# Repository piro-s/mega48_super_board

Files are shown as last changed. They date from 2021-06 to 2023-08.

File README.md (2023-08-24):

## mega48_super_board  
Development board for Atmega48 developed by me and [mostovsky](https://github.com/mostovsky).  
Description for version v0.1 go to [this](docs/mega48_super_board_v0.1.md).  
Description for version v0.2 (some errors) go to [this](docs/mega48_super_board_v0.2.md).  

---
Version 0.3:  
1. Power supply from 7V to 15V or just 5V.  
2. Reverse polarity protection.  
3. There are separate connectors for external power, 5V, 3.3V and ground.  
4. Separate connectors for each pin of the MCU (except reset, xtal and power), compatible with prototyping board.  
5. External quartz at 8 MHz.  
6. Programming via USBasp.  
7. LED to indicate power and reset.  

Board size: 23x71 mm.  
Version 0.3 is the corrected version 0.2.  

---
#### scheme:  
scheme_v0.1:  
[pdf](docs/scheme_v0.1.pdf)  
scheme_v0.3:  
[pdf](docs/scheme_v0.3.pdf)  

---
#### helper:  
helper_v0.1:  
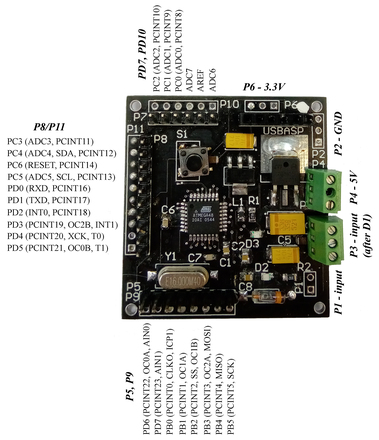
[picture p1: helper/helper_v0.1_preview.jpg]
helper_v0.1
  
helper_v0.3 (also v0.2):  
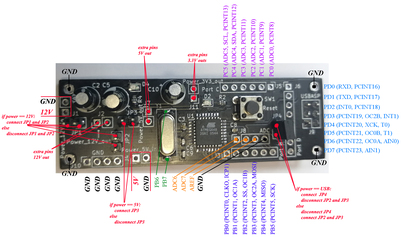
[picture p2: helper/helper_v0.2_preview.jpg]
helper_v0.3
  

---
#### pcb:  
##### pcb_v0.1:  
top screen:  
top_screen  
bottom_screen:  
bottom_screen  
##### pcb_v0.3:  
top screen:  
top_screen  
bottom_screen:  
bottom_screen  

---
#### work:  
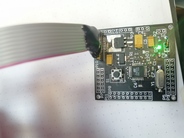
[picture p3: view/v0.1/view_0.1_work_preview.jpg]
work
  
AVRdude:  
AVRdude  

---
#### gerber:  
Archive for production:  
[gerber_v0.1](https://github.com/piro-s/mega48_super_board/raw/main/gerber/mega48_super_board_v0.1.zip)  
[gerber_v0.3](https://github.com/piro-s/mega48_super_board/raw/main/gerber/mega48_super_board_v0.3.zip)

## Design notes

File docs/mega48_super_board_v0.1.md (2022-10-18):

# mega48_super_board  
Development board for Atmega48 developed by me and [mostovsky](https://github.com/mostovsky).  

Version 0.1: 
1. Power supply from 7V to 15V.  
2. There are separate connectors for external power, 5V, 3.3V and ground.  
3. Separate paired connectors for each pin of the MCU (except reset, xtal and power).  
4. Series protection resistors to each output pin.  
5. External quartz at 8 MHz.  
6. Programming via USBasp.  
7. LED to indicate power and reset.  

Version v0.1 fully functional. Board size: 48x45 mm.  

***
## scheme:  
### scheme_v0.1:  
[pdf](scheme_v0.1.pdf)  

***
## helper:  
### helper_v0.1:  
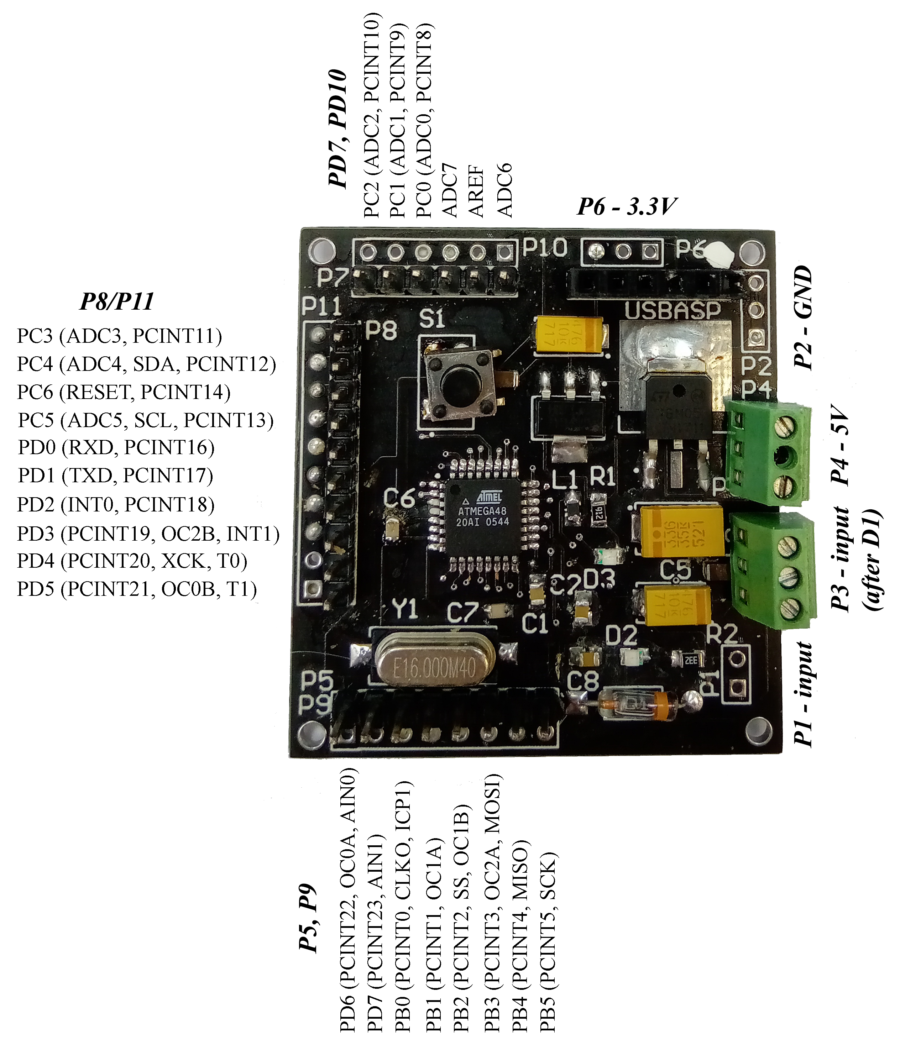
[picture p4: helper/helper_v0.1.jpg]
helper_v0.1
  

***
## pcb:  
### pcb_v0.1:  
#### top screen:  
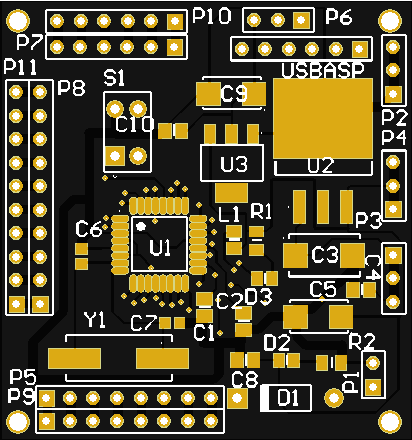
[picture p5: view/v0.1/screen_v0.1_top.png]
top_screen
  
#### top assambled:  
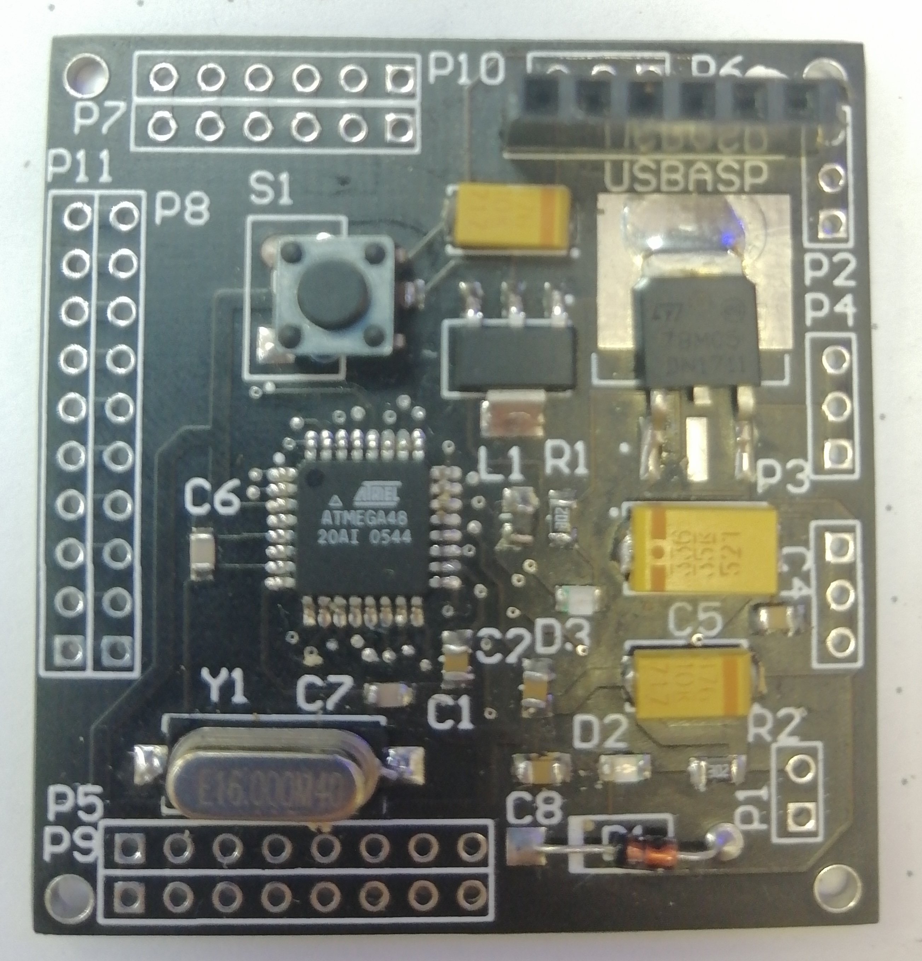
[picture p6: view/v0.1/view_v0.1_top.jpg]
top_assambled
  
#### bottom screen:  
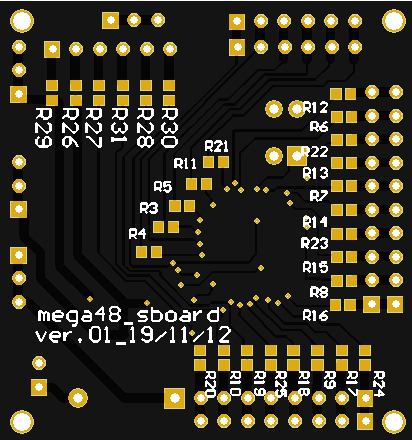
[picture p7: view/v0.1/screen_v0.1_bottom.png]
bottom_screen
  
#### bottom assambled:  
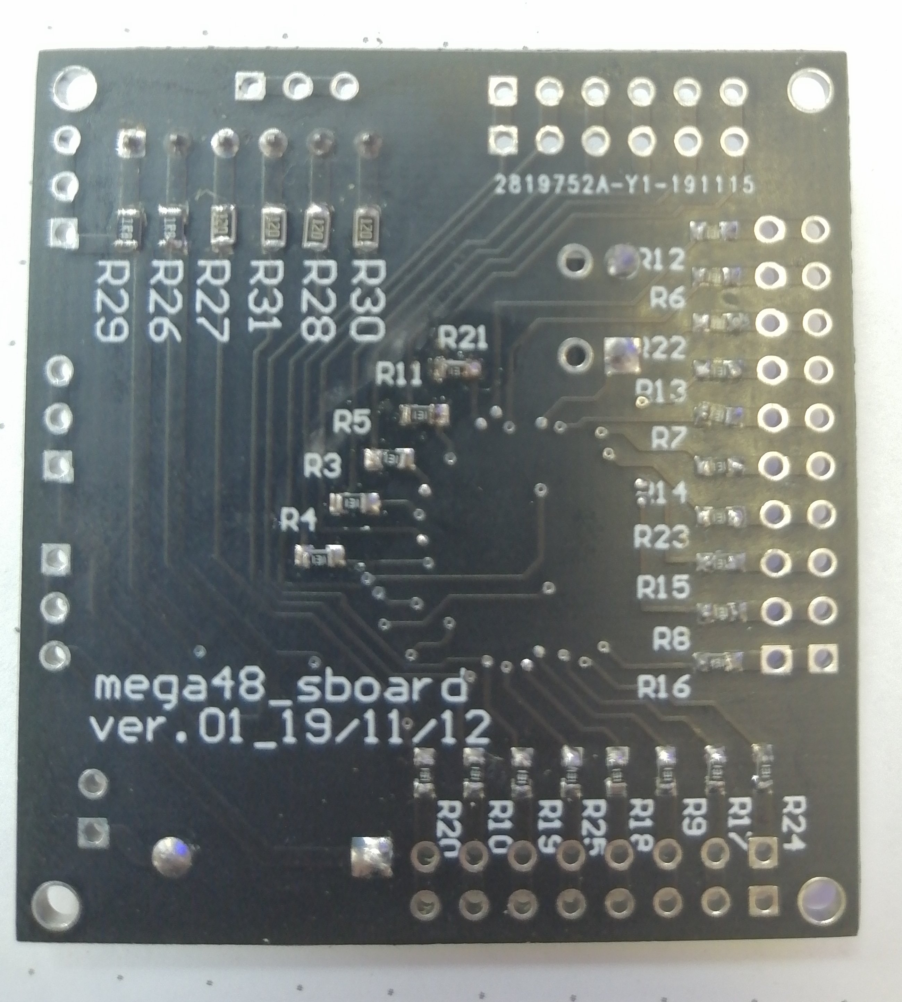
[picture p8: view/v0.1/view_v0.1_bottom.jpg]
bottom_assambled
  

***
## work:  
### work:  
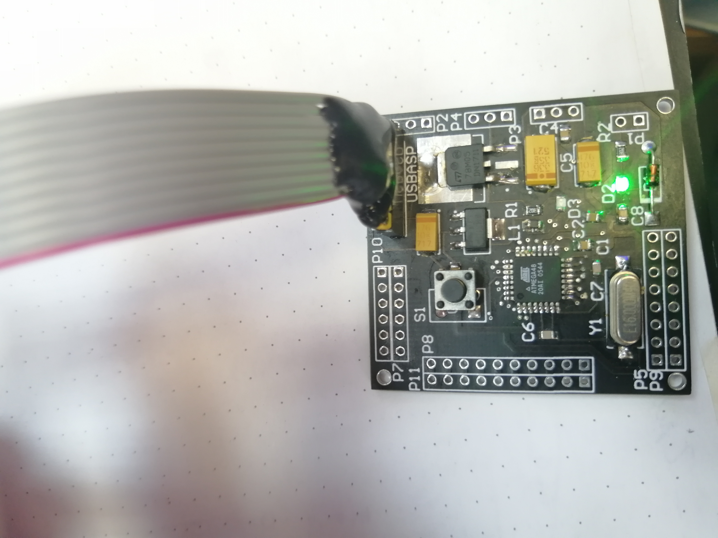
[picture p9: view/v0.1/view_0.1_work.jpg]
work
  
### AVRdude:  
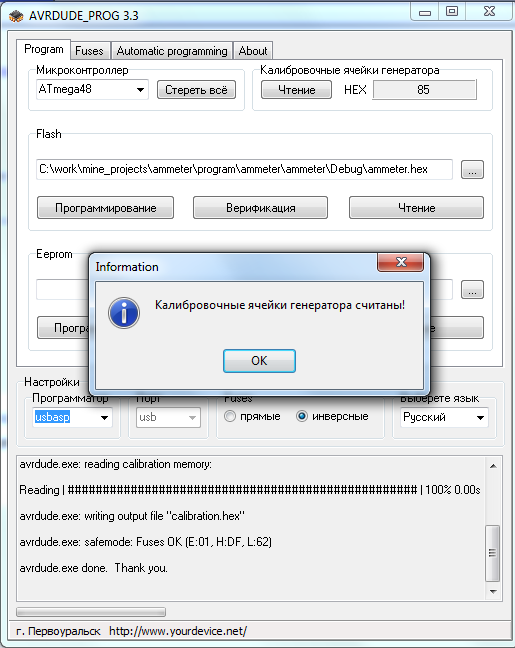
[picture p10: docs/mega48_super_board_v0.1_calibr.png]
AVRdude
  

***
## gerber:  
Archive for production:  
[gerber_v0.1](https://github.com/piro-s/mega48_super_board/raw/main/gerber/mega48_super_board_v0.1.zip)

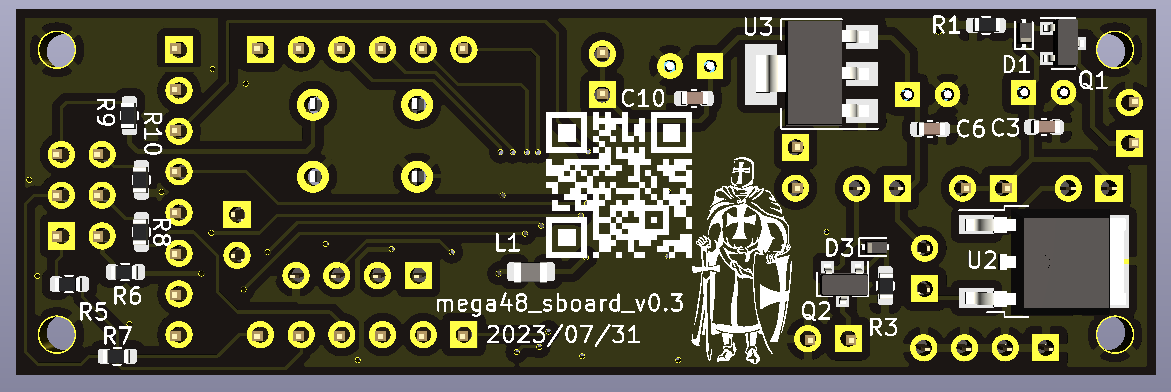
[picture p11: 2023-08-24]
view/v0.3/screen_v0.3_bottom.png

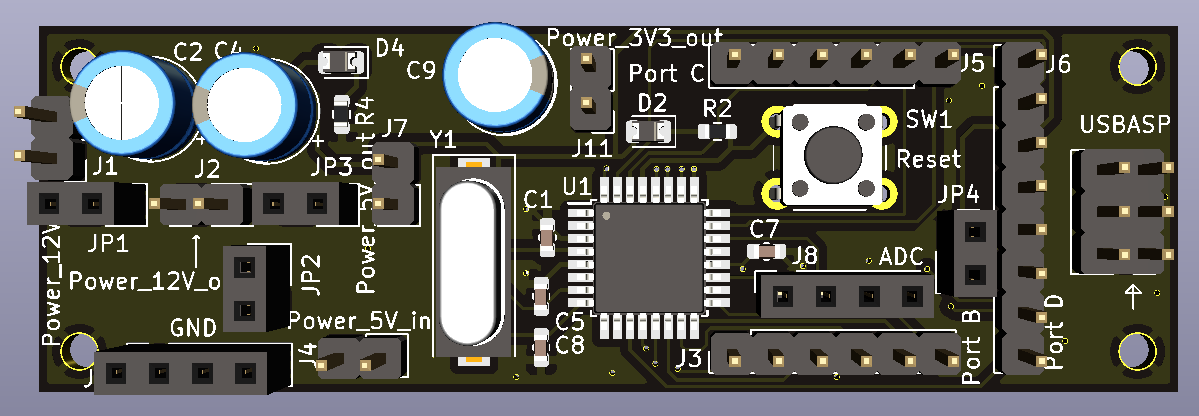
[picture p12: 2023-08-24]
view/v0.3/screen_v0.3_top.png

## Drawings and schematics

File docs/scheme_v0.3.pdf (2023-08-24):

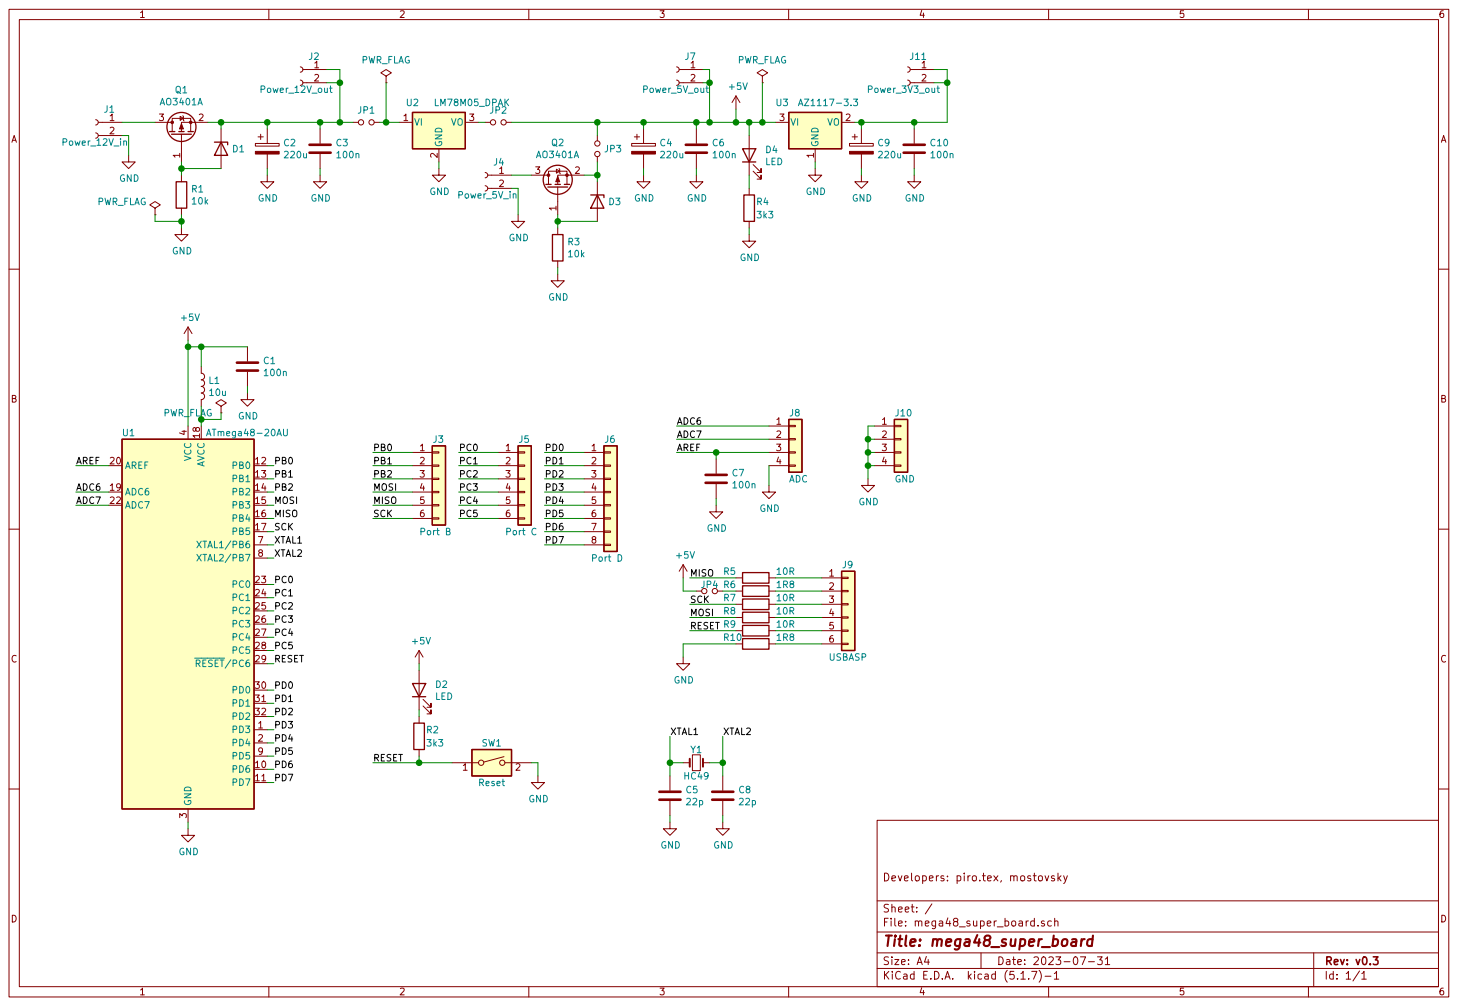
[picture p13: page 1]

File: mega48_super_board.sch Sheet: / Developers: piro.tex, mostovsky

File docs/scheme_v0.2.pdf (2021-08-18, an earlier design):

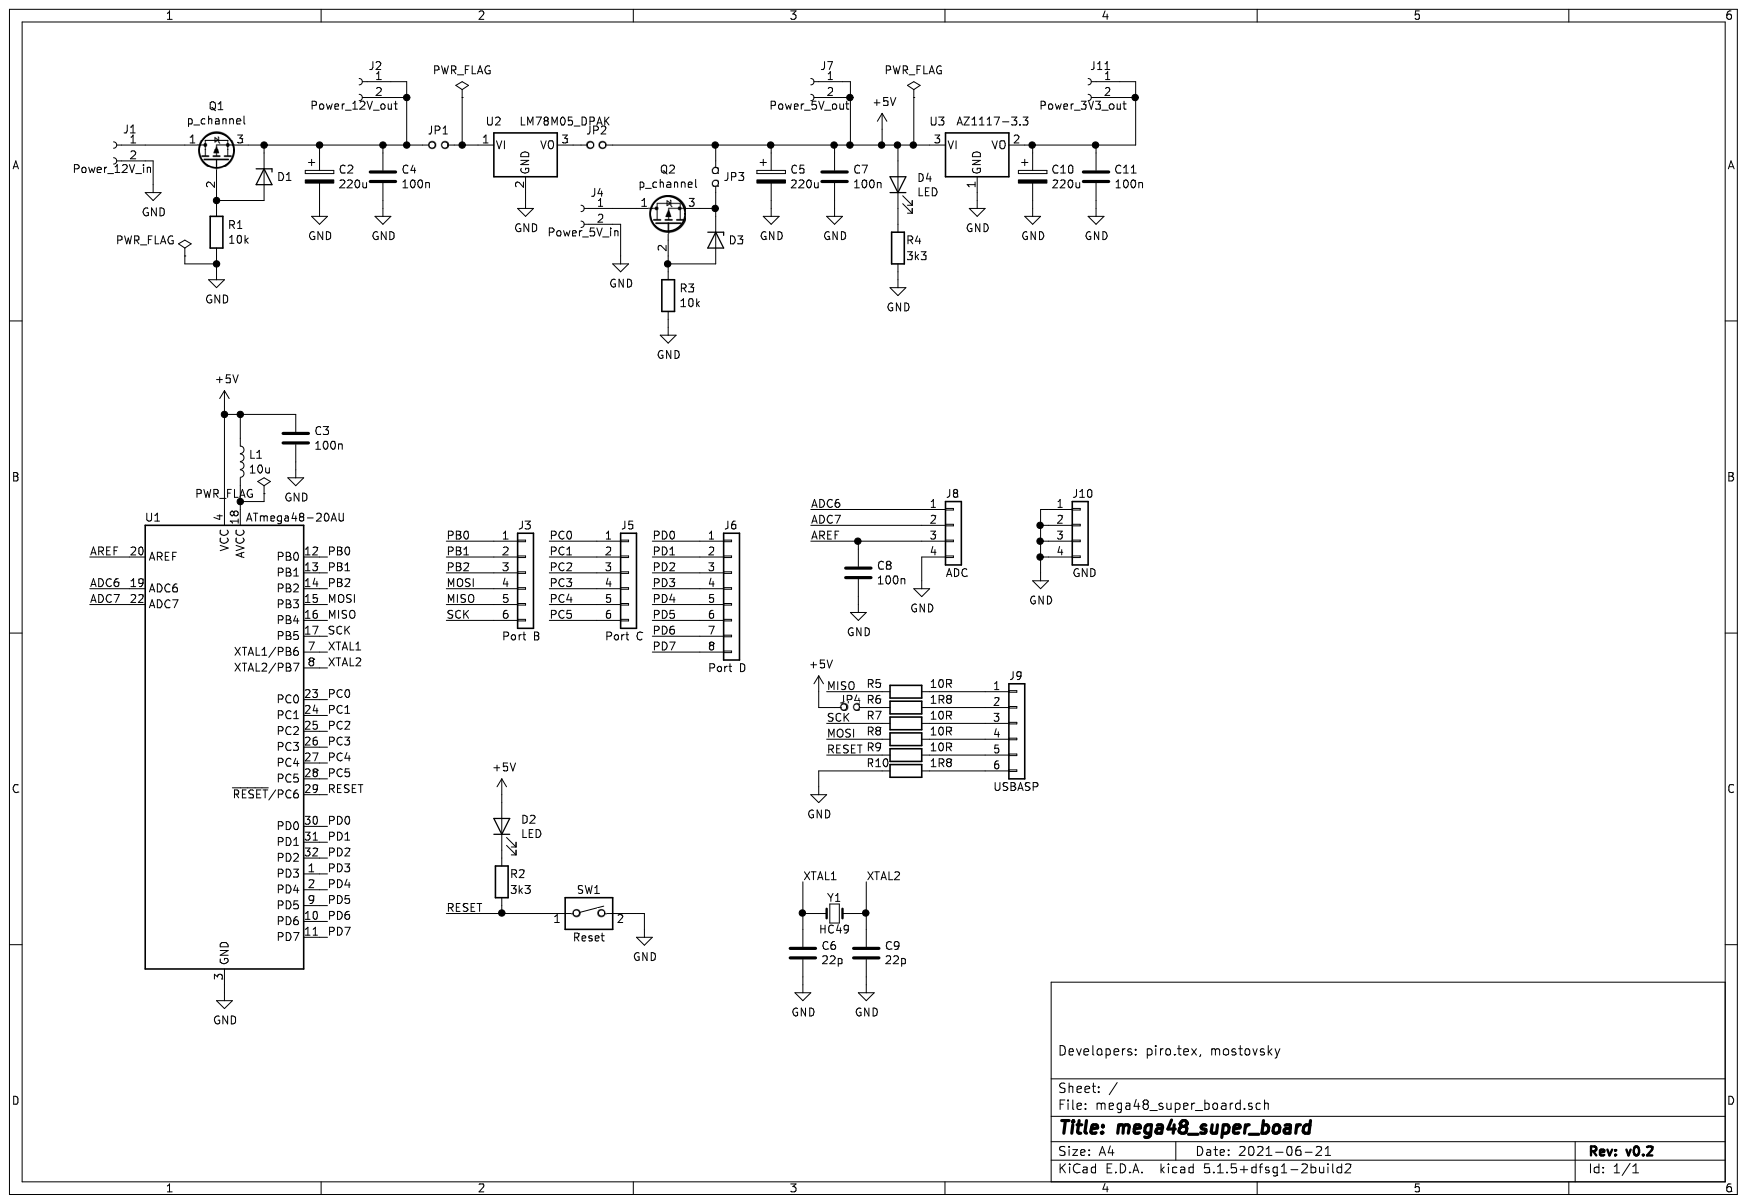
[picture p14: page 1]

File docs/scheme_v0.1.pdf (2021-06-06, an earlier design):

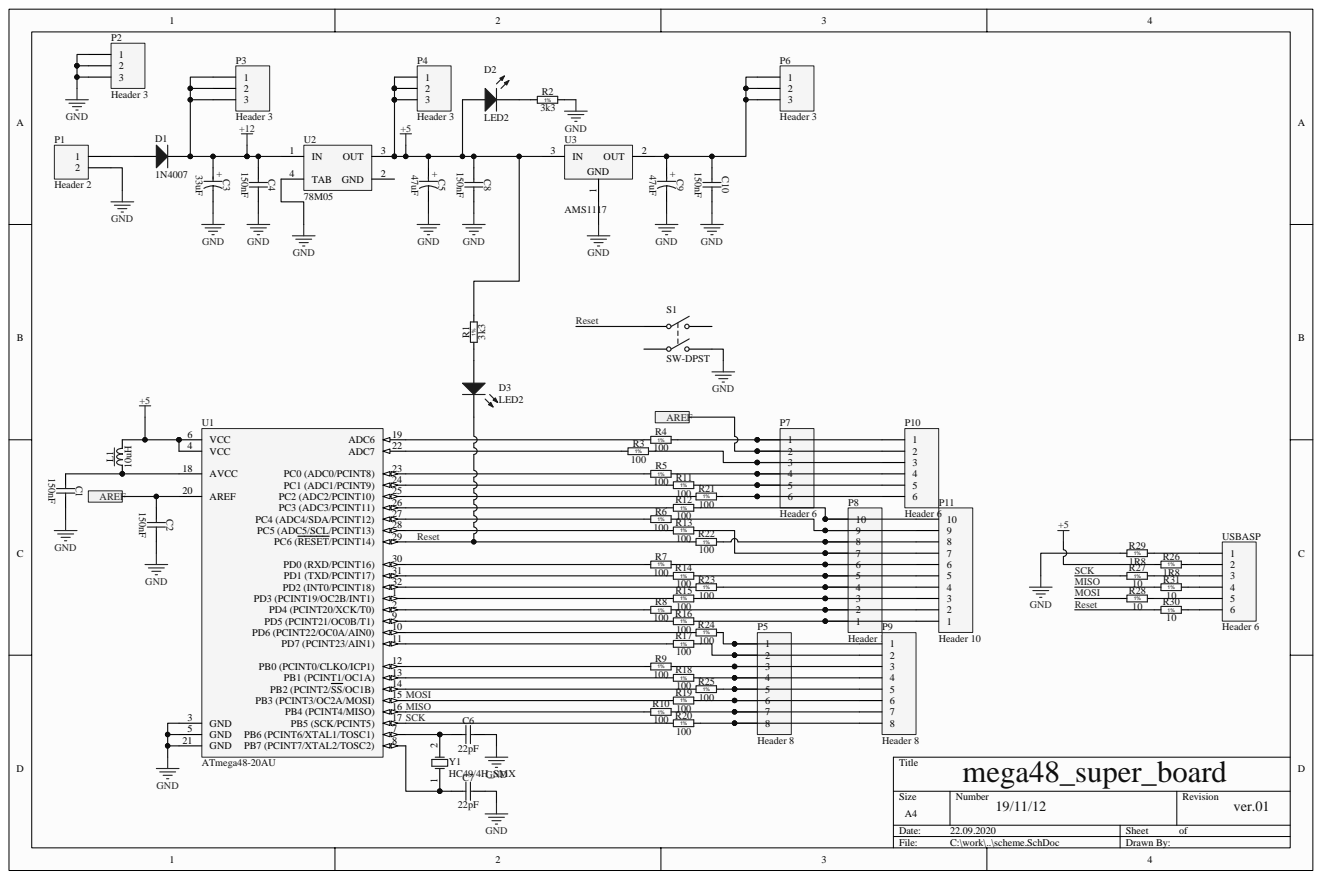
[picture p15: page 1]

1% 100 R6 Header 6 100 1% R13 | 10 9 8 7 6 | Header 6 | 10 9 8 7 6 5 4 3 2 1

1% 100 R15 | 3
1% 100 R8 | 2

MOSI 1% 100 R19 | 6
MISO 1% 100 R10 | 7
100 1% R20 SCK | 8

Size A4 | Number 19/11/12 | Revision ver.01

Date: 22.09.2020 | Sheet of
File: C:\work\..\scheme.SchDoc | Drawn By:

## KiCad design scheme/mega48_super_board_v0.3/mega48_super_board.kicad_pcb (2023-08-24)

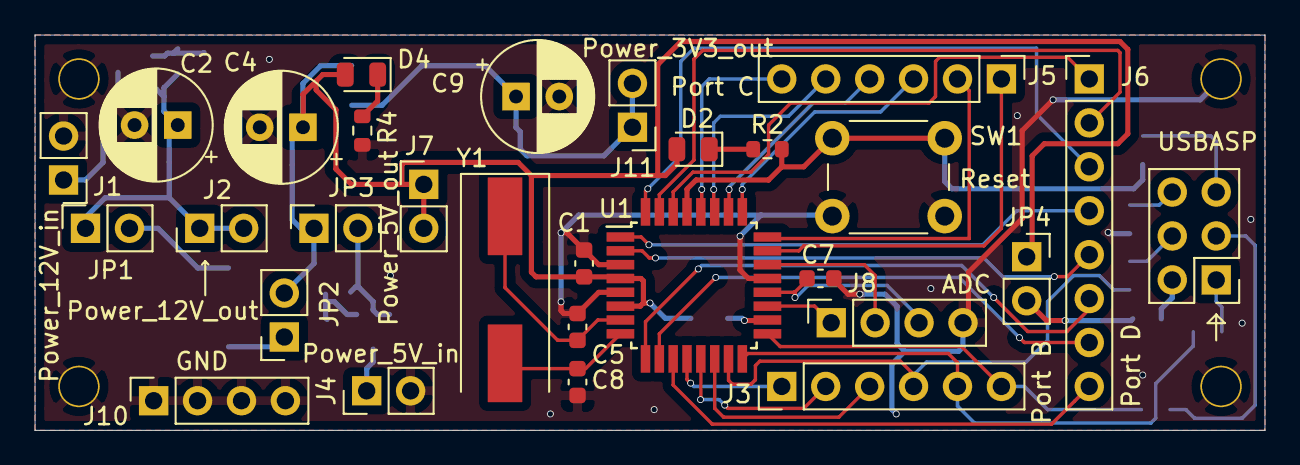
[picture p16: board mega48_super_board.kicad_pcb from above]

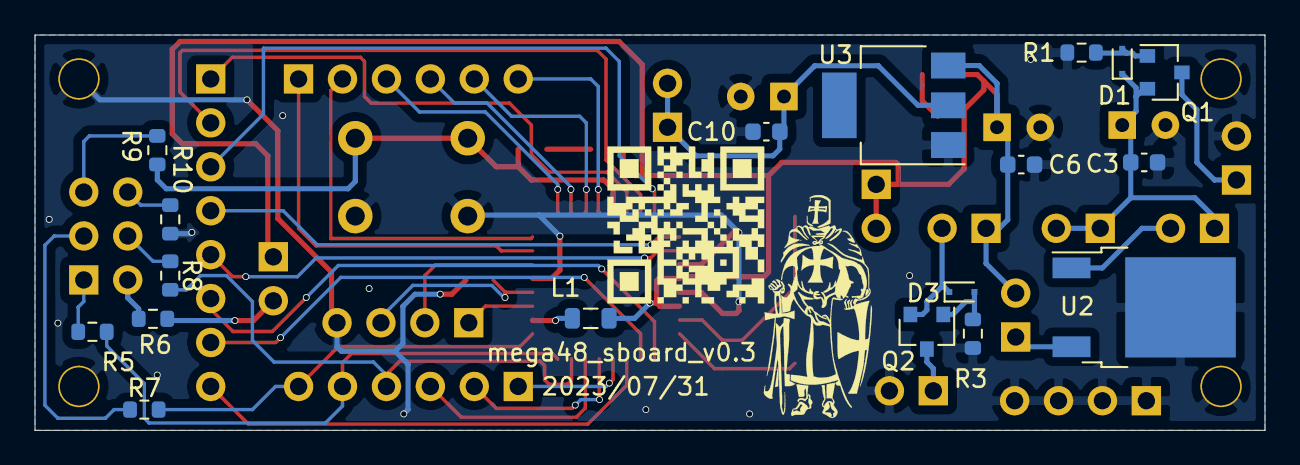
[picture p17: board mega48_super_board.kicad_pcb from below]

Board: 2 copper layers, 71.1 x 22.9 mm, 47 parts (18 on the bottom side), 47 nets.

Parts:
C1, C3, C6, C7, C10: 100n; C_0603_1608Metric
C2, C4, C9: 220u; CP_Radial_D6.3mm_P2.50mm
C5, C8: 22p; C_0603_1608Metric
D1, D3: BZX84Cxx; D_SC-80
D2, D4: LED; D_0805_2012Metric
J1: Power_12V_in; PinHeader_1x02_P2.54mm_Vertical
J2: Power_12V_out; PinHeader_1x02_P2.54mm_Vertical
J3: Port B; PinHeader_1x06_P2.54mm_Vertical
J4: Power_5V_in; PinHeader_1x02_P2.54mm_Vertical
J5: Port C; PinHeader_1x06_P2.54mm_Vertical
J6: Port D; PinHeader_1x08_P2.54mm_Vertical
J7: Power_5V_out; PinHeader_1x02_P2.54mm_Vertical
J8: ADC; PinSocket_1x04_P2.54mm_Vertical
J9: USBASP; PinHeader_2x03_P2.54mm_Vertical
J10: GND; PinSocket_1x04_P2.54mm_Vertical
J11: Power_3V3_out; PinHeader_1x02_P2.54mm_Vertical
JP1, JP2, JP3, JP4: Jumper_NO_Small; PinSocket_1x02_P2.54mm_Vertical
L1: 10u; L_0805_2012Metric
Q1, Q2: AO3401A; SOT-23
R1, R3: 10k; R_0603_1608Metric
R2, R4: 3k3; R_0603_1608Metric
R5, R7, R8, R9: 10R; R_0603_1608Metric
R6, R10: 1R8; R_0603_1608Metric
SW1: Reset; SW_PUSH_6mm
U1: ATmega48-20AU; TQFP-32_7x7mm_P0.8mm
U2: LM78M05_DPAK; TO-252-2
U3: AZ1117-3.3; SOT-223
Y1: HC49; Crystal_SMD_HC49-SD

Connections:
+5V: C1.1, C4.1, C6.1, D2.2, D4.2, J7.1, J7.2, JP2.2, JP3.1, JP4.1, L1.1, U1.4, U1.6, U3.3
/ADC6: J8.1, U1.19
/ADC7: J8.2, U1.22
/AREF: C7.1, J8.3, U1.20
/MISO: J3.5, R5.2, U1.16
/MOSI: J3.4, R8.2, U1.15
/PB0: J3.1, U1.12
/PB1: J3.2, U1.13
/PB2: J3.3, U1.14
/PC0: J5.1, U1.23
/PC1: J5.2, U1.24
/PC2: J5.3, U1.25
/PC3: J5.4, U1.26
/PC4: J5.5, U1.27
/PC5: J5.6, U1.28
/PD0: J6.1, U1.30
/PD1: J6.2, U1.31
/PD2: J6.3, U1.32
/PD3: J6.4, U1.1
/PD4: J6.5, U1.2
/PD5: J6.6, U1.9
/PD6: J6.7, U1.10
/PD7: J6.8, U1.11
/RESET: R2.2, R9.2, SW1.1, U1.29
/SCK: J3.6, R7.2, U1.17
/XTAL1: C5.1, U1.7, Y1.1
/XTAL2: C8.1, U1.8, Y1.2
GND: C1.2, C2.2, C3.2, C4.2, C5.2, C6.2, C7.2, C8.2, C9.2, C10.2, J1.2, J4.2, J8.4, J10.1, J10.2, J10.3, J10.4, R1.2, R3.2, R4.2, R10.2, SW1.2, U1.3, U1.5, U1.21, U2.2, U3.1
unnamed: C2.1, C3.1, D1.1, J2.1, J2.2, JP1.1, Q1.2
unnamed: C9.1, C10.1, J11.1, J11.2, U3.2
unnamed: D1.2, Q1.1, R1.1
unnamed: D2.1, R2.1
unnamed: D3.1, JP3.2, Q2.2
unnamed: D3.2, Q2.1, R3.1
unnamed: D4.1, R4.1
unnamed: J1.1, Q1.3
unnamed: J4.1, Q2.3
unnamed: J9.1, R5.1
unnamed: J9.2, R6.1
unnamed: J9.3, R7.1
unnamed: J9.4, R8.1
unnamed: J9.5, R9.1
unnamed: J9.6, R10.1
unnamed: JP1.2, U2.1
unnamed: JP2.1, U2.3
unnamed: JP4.2, R6.2
unnamed: L1.2, U1.18

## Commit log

2021-06-06 Upload v0.1
    [PCB1.PcbDoc, mega48_super_board.PrjPcb, scheme.SchDoc]
2021-08-18 Upload v0.2
    [mega48_super_board.kicad_pcb, mega48_super_board.sch]
2021-08-18 Fix gerber links
2023-05-30 fix: helper_v0.1, reverse PD7,PD10
    Corrected the designation of the pins of the connector PD7, PD10.
2023-08-24 fix: Version 0.3
    Fix errors made in v0.2:
    1. The connector for programming must be soldered
    on the bottom side so that you can start the
    USBasp programmer, or solder a new cable for the
    programmer yourself.
    2. Transistors Q1 and Q2 must be upside-down
    soldered.
    [mega48_super_board.kicad_pcb, mega48_super_board.sch]
